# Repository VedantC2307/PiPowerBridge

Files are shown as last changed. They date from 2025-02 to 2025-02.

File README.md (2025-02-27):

# PiPowerBridge

A power distribution PCB designed to manage power delivery for a Raspberry Pi and ODrive motor controller. The board is specifically optimized to mount directly on top of the ODrive controller for a compact and integrated solution.

## Features ⚡

- Input Voltage: 33V (LiPo battery) 🔋
- Output: 
  - 5V DC regulated output for Raspberry Pi 
  - Direct power distribution to ODrive motor controller 
- Form factor optimized for direct mounting on top of ODrive
- Additional SPI interface pins for connecting external devices 🔌

## Description 📝
This PCB converts 33V input from a LiPo battery to 5V to power for the Raspberry Pi, while also directly powering the ODrive motor controller. 
It’s designed to stack directly on top of the controller, saving space and keeping the setup tidy. It includes an additional SPI interface pins for easily connecting external sensors like encoder.

## PCB Design 🎨

### 3D Model View 🖥️
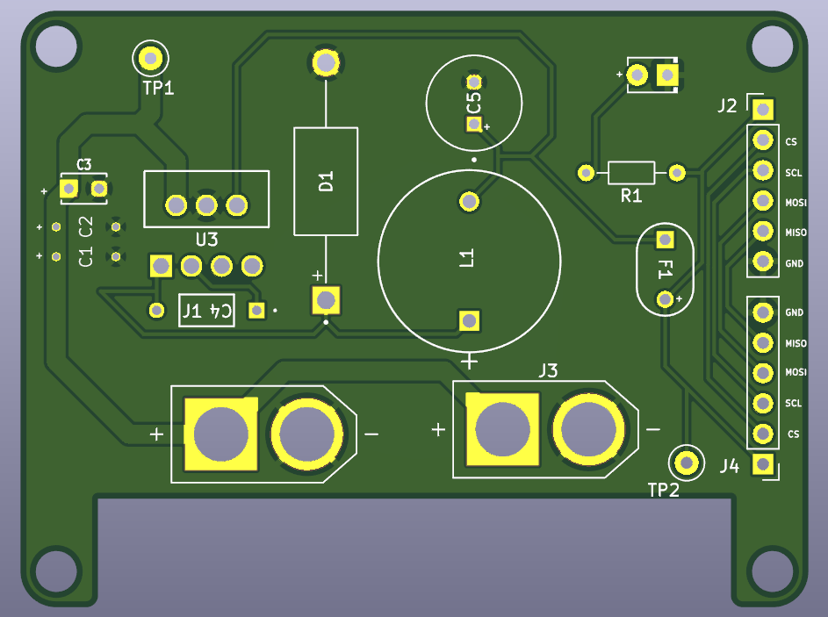
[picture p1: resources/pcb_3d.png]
3D Model of the PCB


### PCB Layout 📐
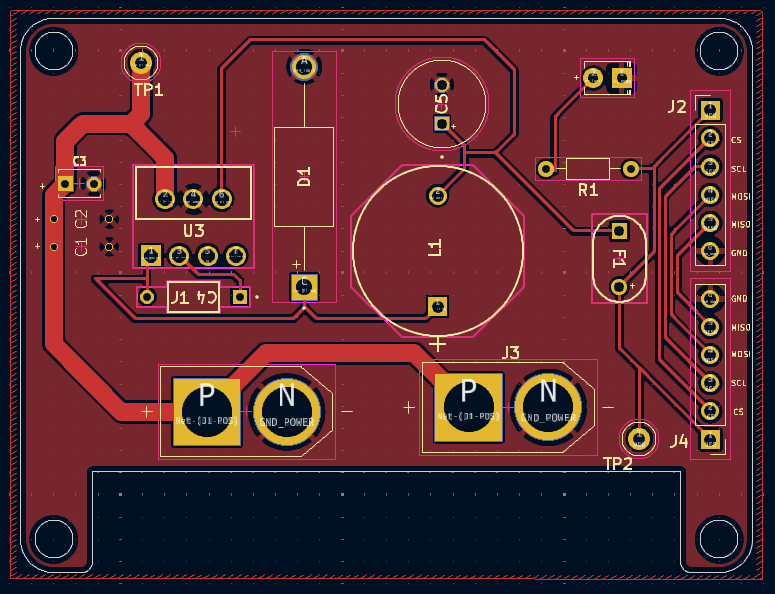
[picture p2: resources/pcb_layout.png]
PCB Layout Design


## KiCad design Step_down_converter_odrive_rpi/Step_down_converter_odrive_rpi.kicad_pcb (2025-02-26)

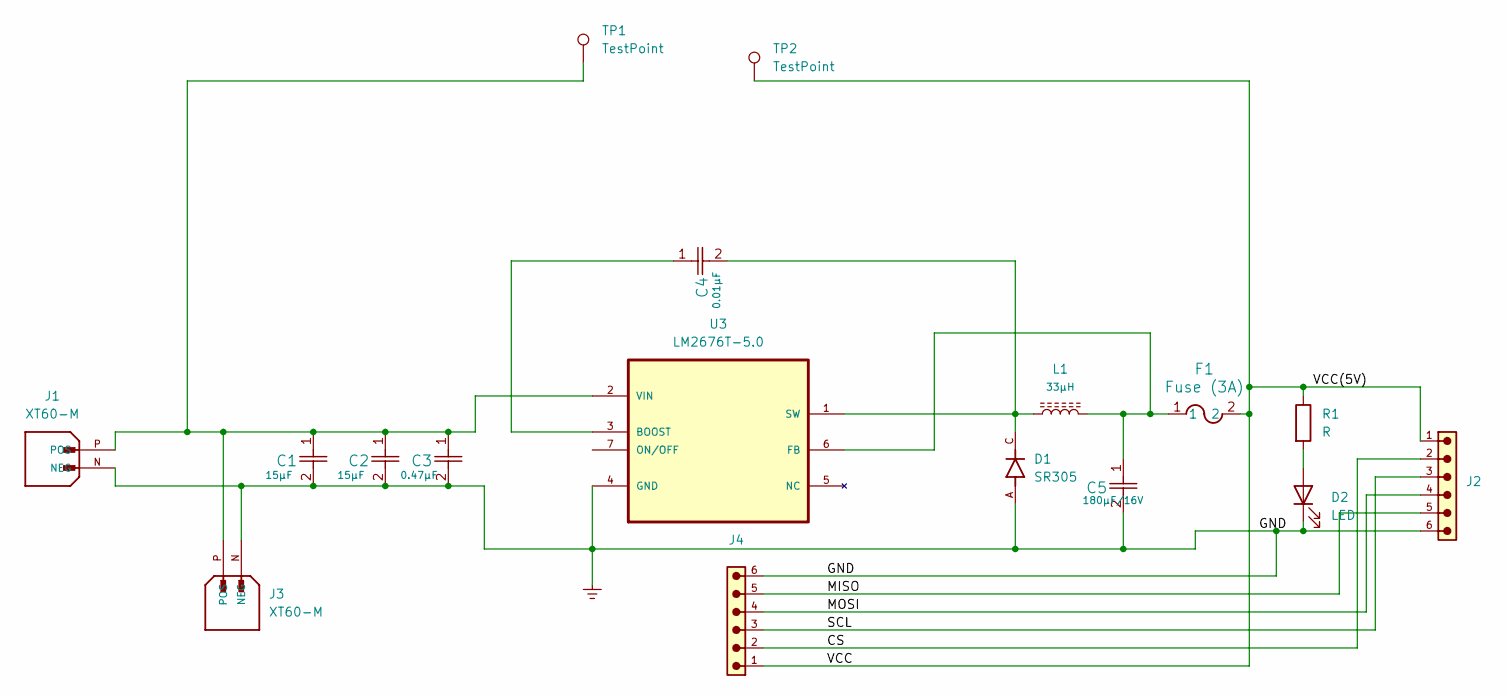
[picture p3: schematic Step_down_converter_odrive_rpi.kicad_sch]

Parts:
C1, C2: 15µF; PCB capacitor 15uF
C3: 0.47µF; CAPRR254W54L381T254H466
C4: 0.01µF; CAP_C410C_AX_Z5U_U5TA_KEM
C5: 180µF/16V; CAPPRD350W60D800H1200
D1: SR305; DIOAD1990W125L900D530; PARTREV K2105
D2: LED; LED_D2.0mm_W4.0mm_H2.8mm_FlatTop
F1: Fuse (3A); FUSE_CMF-RL50A-0_BRN
J1, J3: XT60-M; AMASS_XT60-M; PARTREV V1.2
J2, J4: PinHeader_1x06_P2.54mm_Vertical; PART-NUMBER 61300611121
L1: 33µH; IND_SBC8-330-452_KEM
R1: R; R_Axial_DIN0204_L3.6mm_D1.6mm_P7.62mm_Horizontal
TP1, TP2: TestPoint; TestPoint_Loop_D2.50mm_Drill1.0mm_LowProfile
U3: LM2676T-5.0; TA07B; MPN LM2676T-5.0

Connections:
/CS: J2.2, J4.2
/MISO: J2.5, J4.5
/MOSI: J2.4, J4.4
/SCL: J2.3, J4.3
/VCC: F1.2, J2.1, J4.1, R1.1, TP2.1
GND_POWER: C1.2, C2.2, C3.2, C5.2, D1.A, D2.1 (K), J1.N (NEG), J2.6, J3.N (NEG), J4.6, U3.4 (GND)
unnamed: D2.2 (A), R1.2
unnamed: C1.1, C2.1, C3.1, J1.P (POS), J3.P (POS), TP1.1, U3.2 (VIN)
unnamed: C4.1, U3.3 (BOOST)
unnamed: C5.1, F1.1, L1.2, U3.6 (FB)
unnamed: C4.2, D1.C, L1.1, U3.1 (SW)

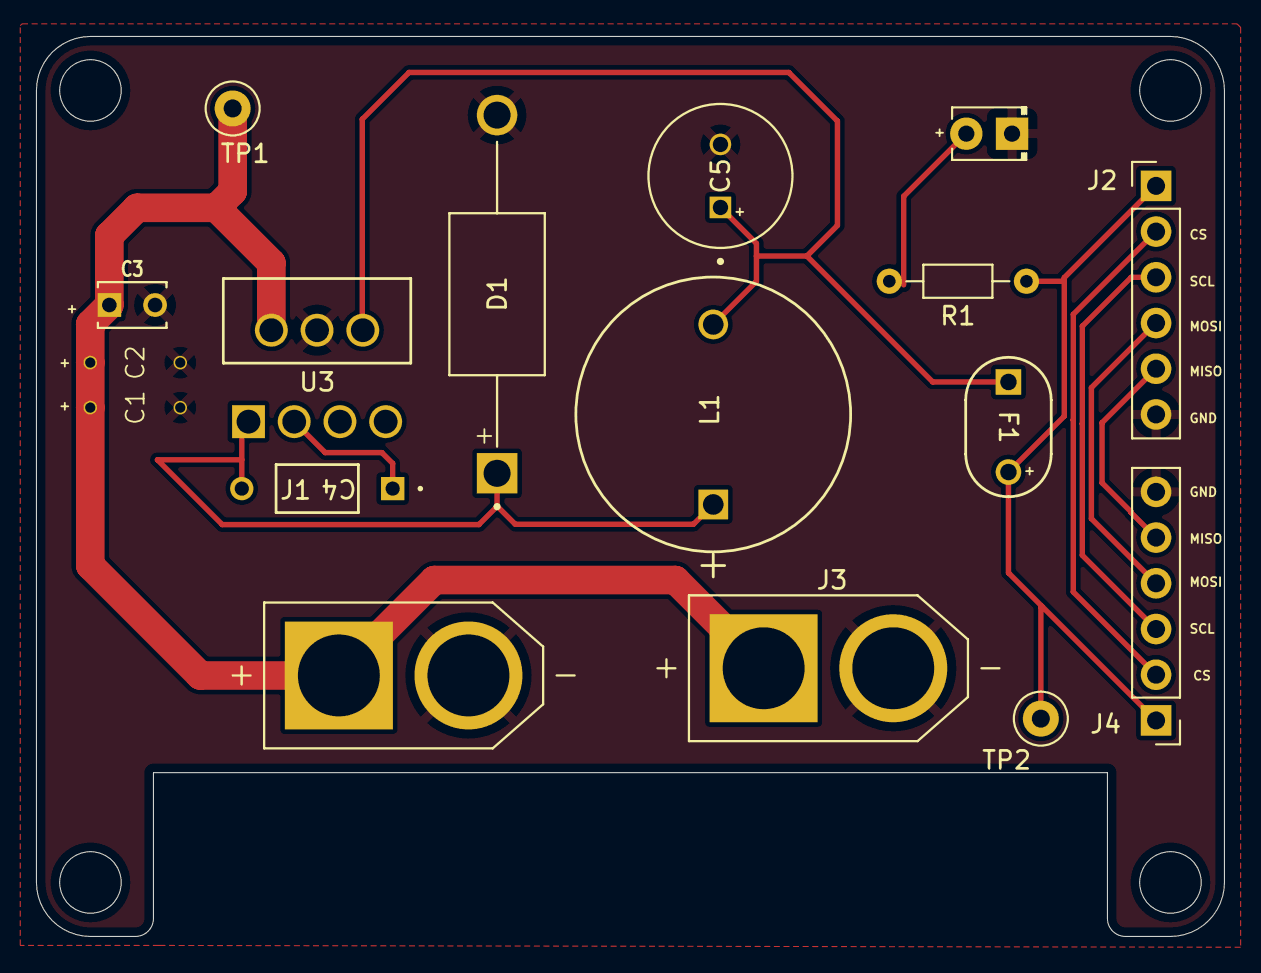
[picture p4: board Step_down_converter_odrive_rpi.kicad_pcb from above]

Board: 2 copper layers, 66.0 x 50.0 mm, 17 parts (0 on the bottom side), 11 nets.
